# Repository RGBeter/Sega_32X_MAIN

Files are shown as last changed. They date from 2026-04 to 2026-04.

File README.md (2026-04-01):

# Sega_32X_MAIN
Reproduction of 32X MAIN based on official sega service documents and Cosam's Neptune work

This board has been dubbed "VA2" as that was the name sega called the planned 32X with integrated bodge capacitors

# Build Notes
These PCBs are tested to work with with a stock MARS SUB pcb, building these requires skills in microsoldering, QFP soldering, hot air rework, and Mega Drive/32X troubleshooting. It is highly recomendded you start with a set of known working parts from a donor 32X. This board is based off of a scanned VA1 32X PCB, but with built in bodge capacitors and resistors including C96, C97 and R66. RGBeter does not officially offer any debugging service or aid in building these PCBs.

In order to ensure reliability and no damage to mega drives this is installed in, you MUST order these PCBs with an edge bevel, and it is highly recomended that they recieve hard gold plating on said edge connector. When this is done, it may be difficult to solder to the 

# Bodge Instructions
32X bodge wires are POTENTIALLY eliminated with use of this PCB, however, knowledge of how YOUR 32X sub board is wired greatly dictates the required bodge wires, the following assumes you are using a STOCK 32X sub:

PHOTOS COMING SOON

1. Leave both the VCLK and AS jumpers OPEN
2. Install a wire between the AS point on the bottom of MAIN near the card edge, and the AS point on 32X SUB
3. Install a wire between the bodge resistor on C94 and the NON-Ground side of C53
4. Install a wire from Pin B13 of CN2 and pin 3 of IC15
5. Install a shielded wire from the top side of FB1 to the through hole labeled VCLK on SUB, with the shield soldered to a ground nearby

# BOM Notes
C96 and C97 should be omitted if you utilize a Gate Array 32x Interface chip (315-5818). If you utilize an SCA based 32X Interface chip (315-5818A) said capacitors should be 47pF when usiing 23MHz rated SH-2s and 100pF on 28MHz rated SH-2s.

# Special Thanks
Cosam, and all people involved in the Neptune project for both the inspiration, and the schematic drawings used in this project. Said schematics were modified to match a stock 32X.

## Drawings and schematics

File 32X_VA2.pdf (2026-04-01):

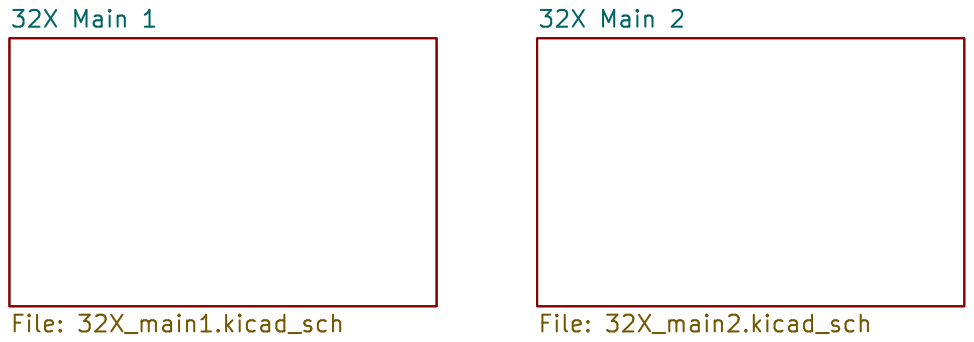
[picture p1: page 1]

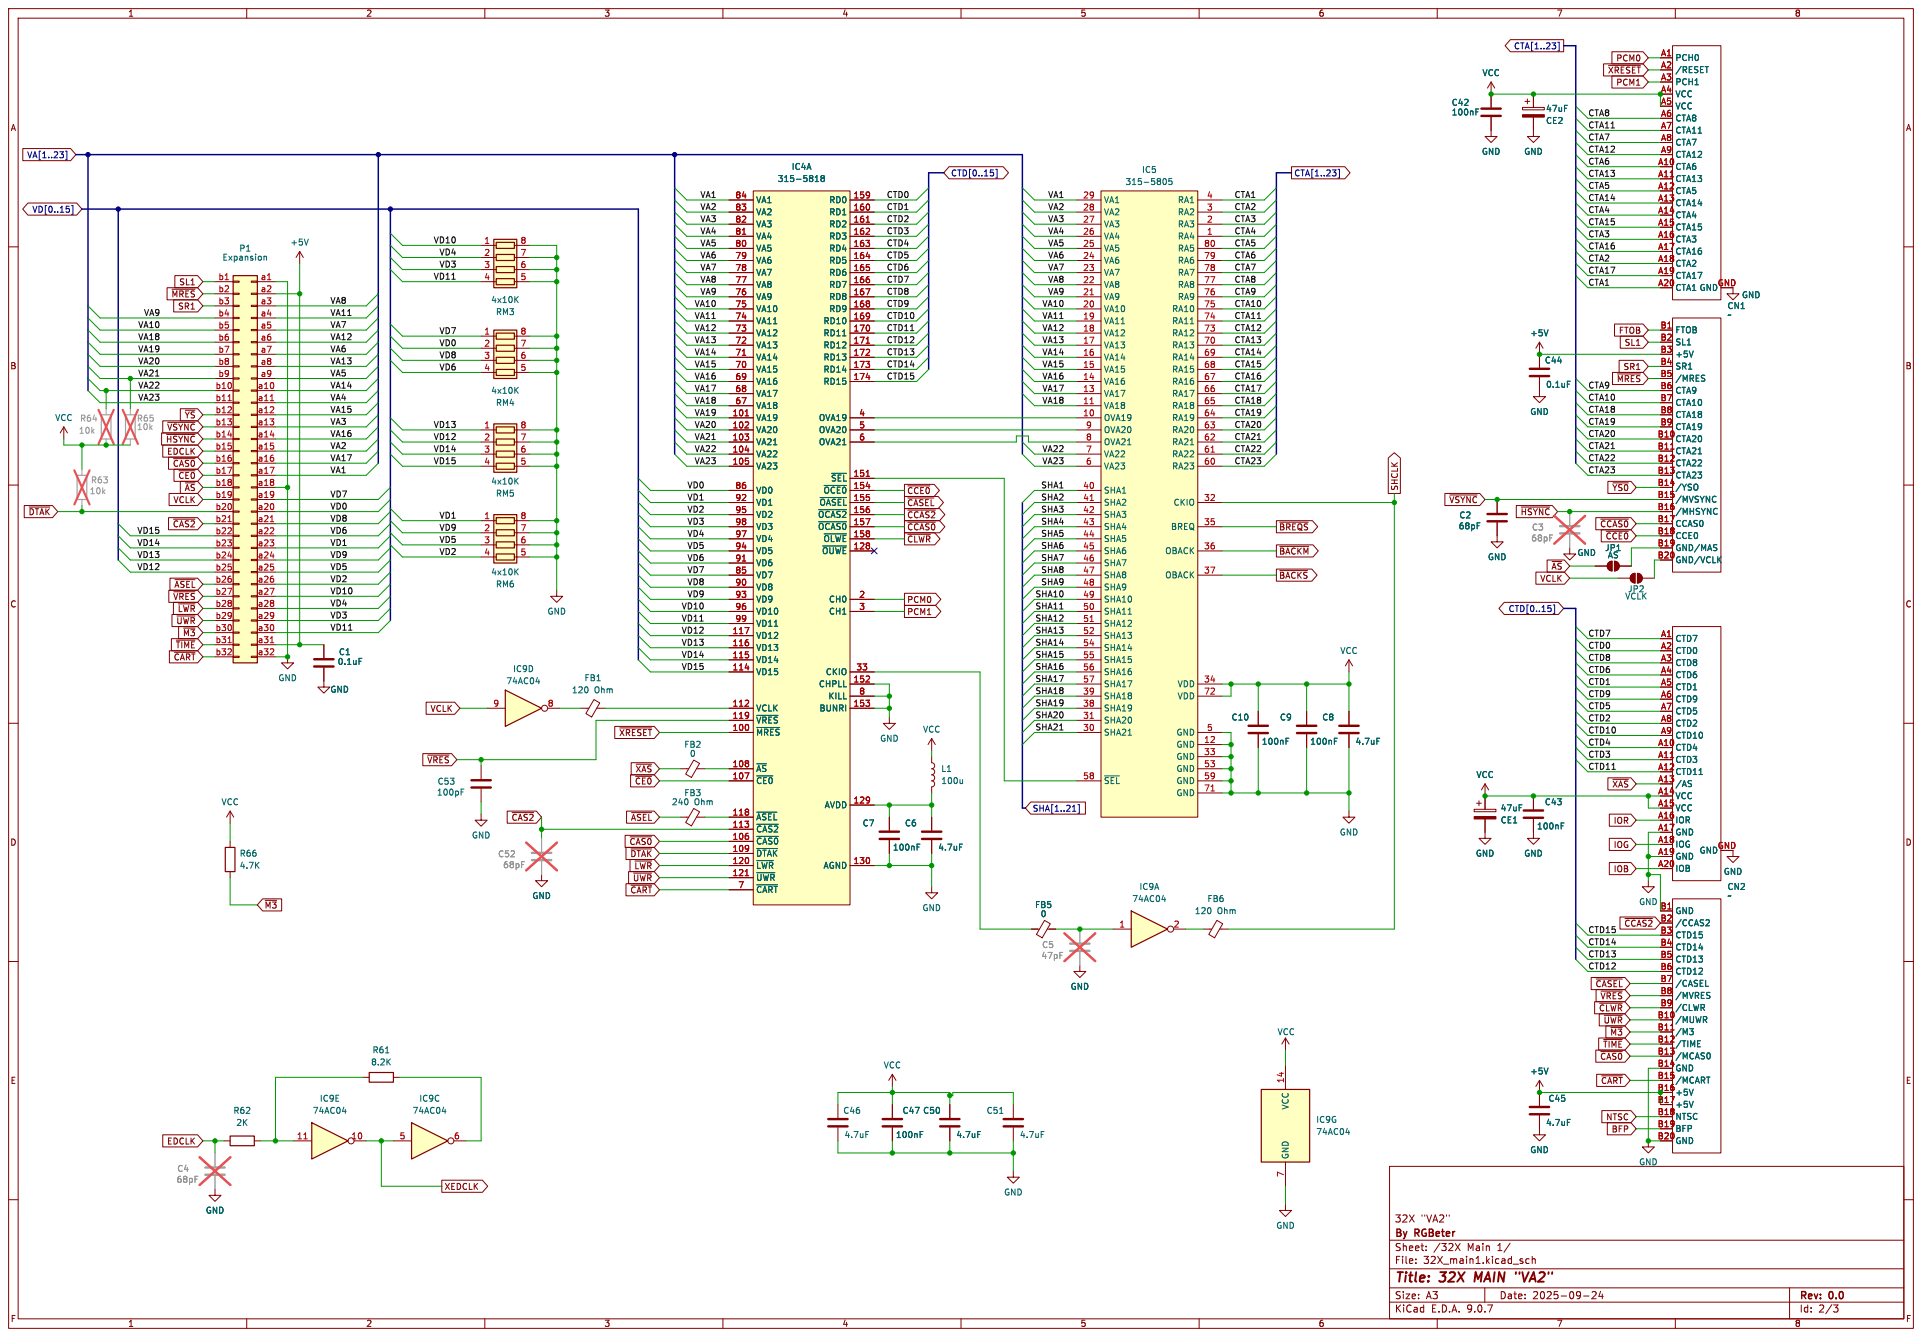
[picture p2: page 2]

315-5818 VA1 84 VA2 83 VA3 82 VA4 81 VA5 80 VA6 79 VA7 78 VA8 77 VA9 76 VA10 75 VA11 74 VA12 73 VA13 72 VA14 71 VA15 70 VA16 69 VA17 68 VA18 67 VA19 101 VA20 102 VA21 103 VA22 104 VA23 105 VD0 86 VD1 92 VD2 95 VD3 98 VD4 97 VD5 94 VD6 91 VD7 85 VD8 90 VD9 93 VD10 96 VD11 99 VD12 117 VD13 116 VD14 115 VD15 114 VCLK 112 ~{VRES} 119 ~{MRES} 100 ~{AS} 108 ~{CE0} 107 ~{ASEL} 118 ~{CAS2} 113 ~{CAS0} 106 ~{DTAK} 109 ~{LWR} 120 ~{UWR} 121 ~{CART} 7
315-5805 VA1 84 VA2 83 VA3 82 VA4 81 VA5 80 VA6 79 VA7 78 VA8 77 VA9 76 VA10 75 VA11 74 VA12 73 VA13 72 VA14 71 VA15 70 VA16 69 VA17 68 VA18 67 VA19 101 VA20 102 VA21 103 VA22 104 VA23 105 VD0 86 VD1 92 VD2 95 VD3 98 VD4 97 VD5 94 VD6 91 VD7 85 VD8 90 VD9 93 VD10 96 VD11 99 VD12 117 VD13 116 VD14 115 VD15 114 VCLK 112 ~{VRES} 119 ~{MRES} 100 ~{AS} 108 ~{CE0} 107 ~{ASEL} 118 ~{CAS2} 113 ~{CAS0} 106 ~{DTAK} 109 ~{LWR} 120 ~{UWR} 121 ~{CART} 7

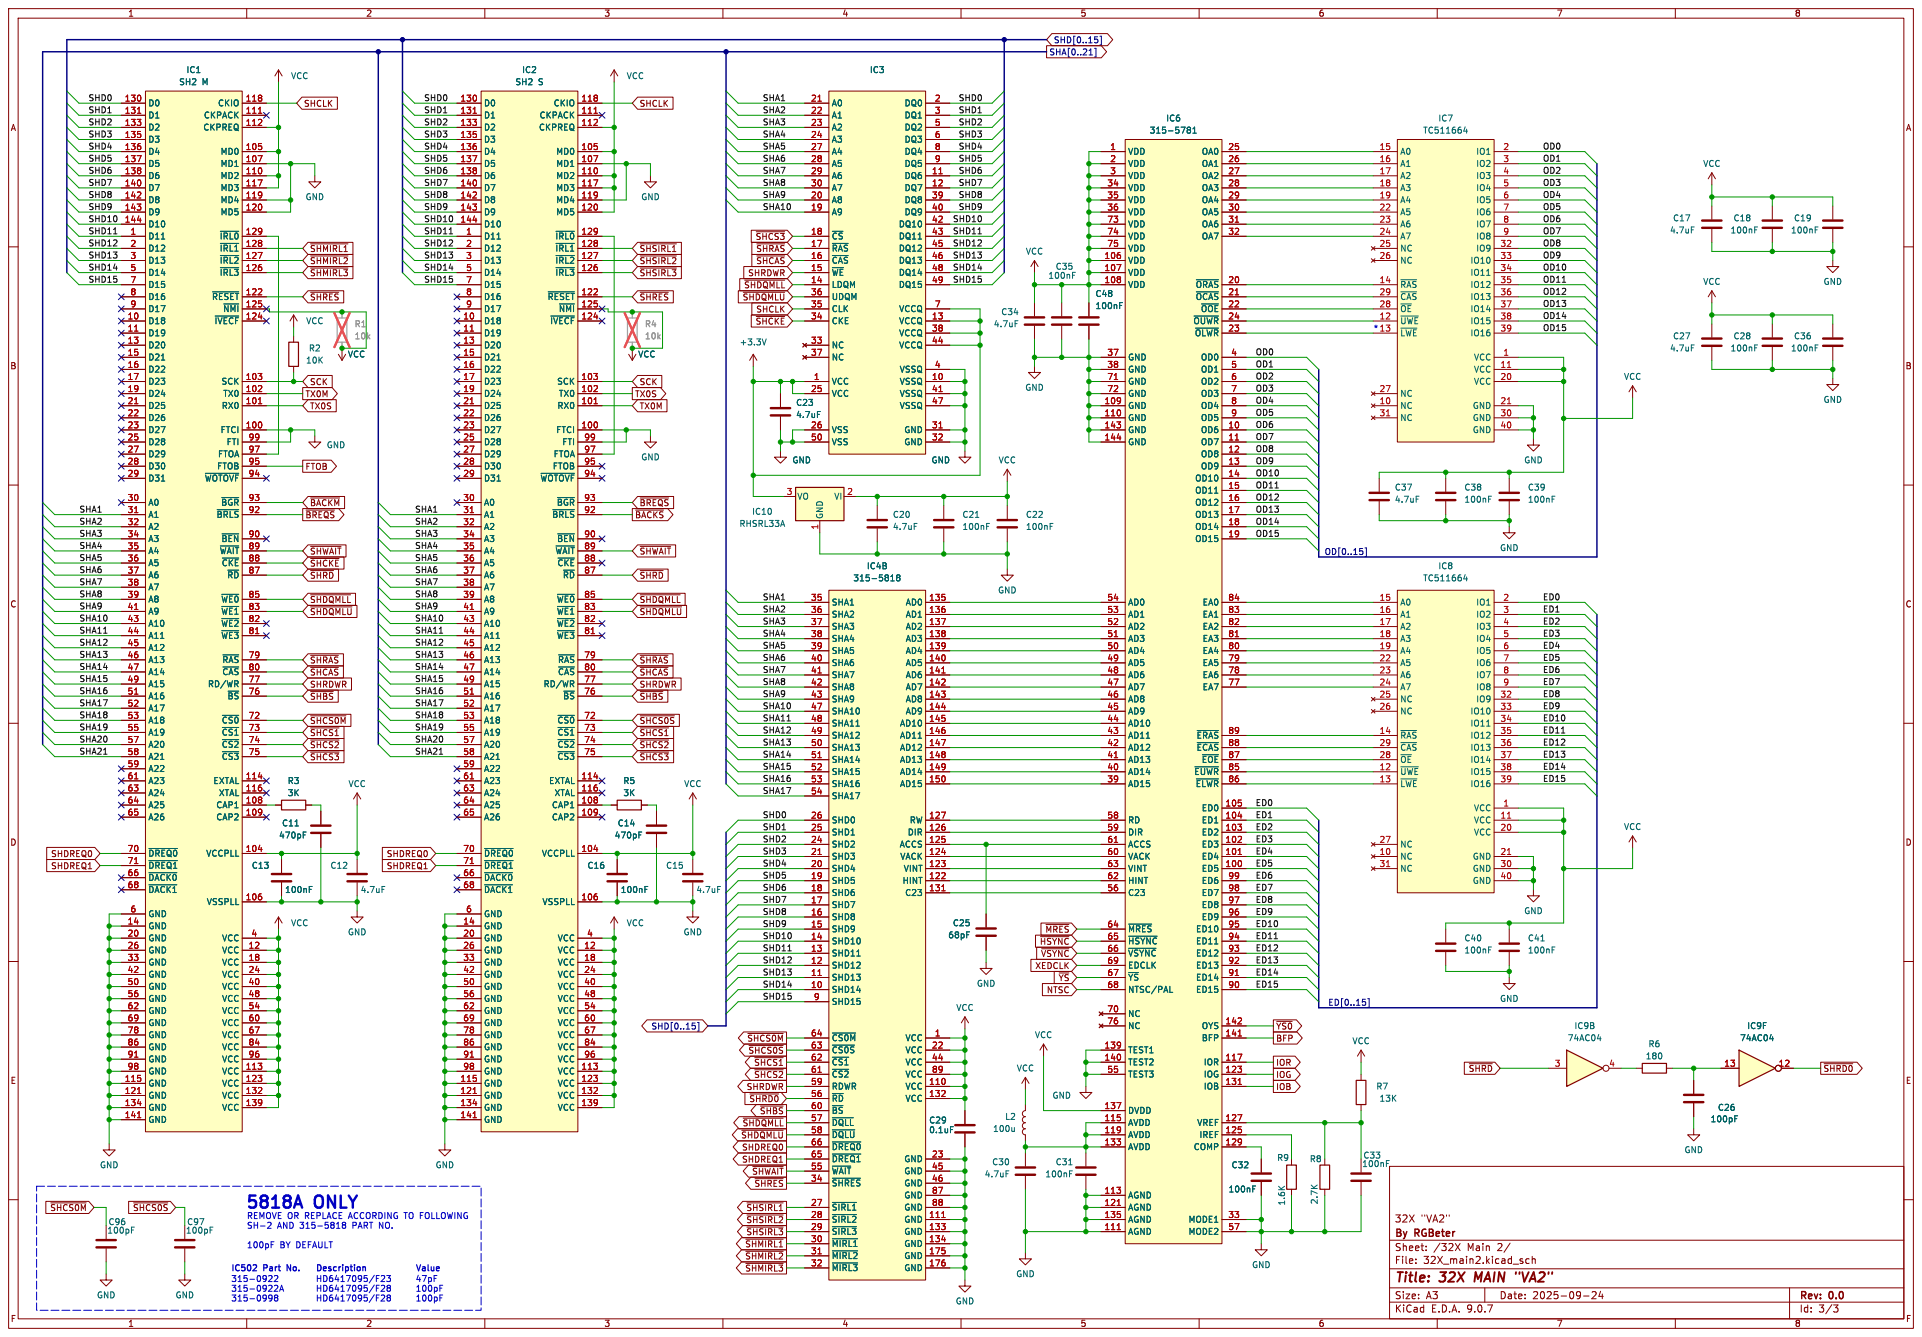
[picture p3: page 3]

GND
AD0 135 AD1 136 AD2 137 AD3 138 AD4 139 AD5 140 AD6 141 AD7 142 AD8 143 AD9 144 AD10 145 AD11 146 AD12 147 AD13 148 AD14 149 AD15 150 RW 127 DIR 126 ACCS 125 VACK 124 VINT 123 HINT 122 C23 131 VCC 1 VCC 22 VCC 44 VCC 89 VCC 110 VCC 132 GND 23 GND 45 GND 46 GND 87 GND 88 GND 111 GND 133 GND 134 GND 175 GND 176

AD0 135 AD1 136 AD2 137 AD3 138 AD4 139 AD5 140 AD6 141 AD7 142 AD8 143 AD9 144 AD10 145 AD11 146 AD12 147 AD13 148 AD14 149 AD15 150 RW 127 DIR 126 ACCS 125 VACK 124 VINT 123 HINT 122 C23 131 VCC 1 VCC 22 VCC 44 VCC 89 VCC 110 VCC 132 GND 23 GND 45 GND 46 GND 87 GND 88 GND 111 GND 133 GND 134 GND 175 GND 176 C29

A0 15 A1 16 A2 17 A3 18 A4 19 A5 22 A6 23 A7 24 NC 25 NC 26 ~{RAS} 14 ~{CAS} 29 ~{OE} 28 ~{UWE} 12 ~{LWE} 13 NC 27 NC 10 NC 31

100pF REMOVE OR REPLACE ACCORDING TO FOLLOWING
